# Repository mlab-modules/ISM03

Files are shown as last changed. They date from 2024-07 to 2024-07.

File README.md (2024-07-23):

# ISM03 - Si4463-based transceiver with SPI interface

The ISM03 is a high-performance wireless transceiver designed for long-distance data transmission. The module is based on the [Si4463 chip](https://www.silabs.com/wireless/proprietary/ezradiopro-sub-ghz-ics/device.si4463?tab=specs) from Silicon Labs. It has a wide frequency range and output power, it is ideal for applications that require robust and reliable wireless communication.

ISM03 can operate on the open 433 or 868 MHz frequencies, which are popular in many applications.

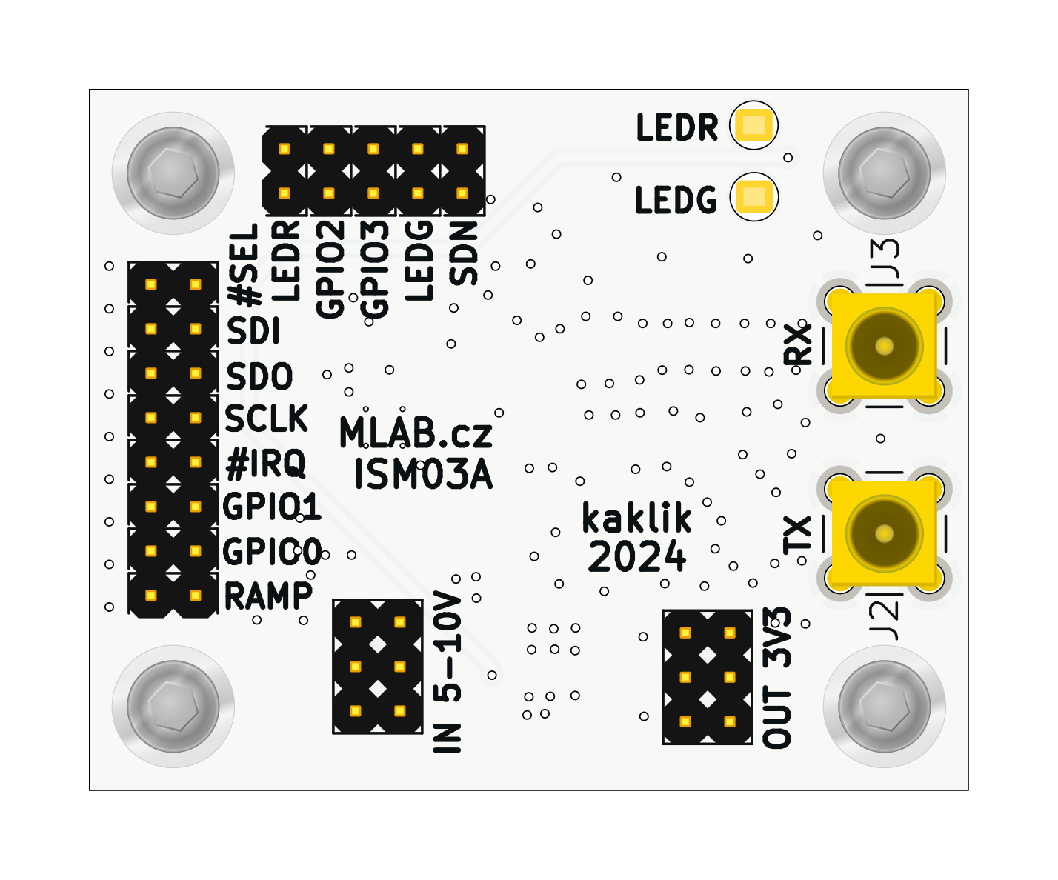
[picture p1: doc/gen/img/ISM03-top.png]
Top view on ISM03

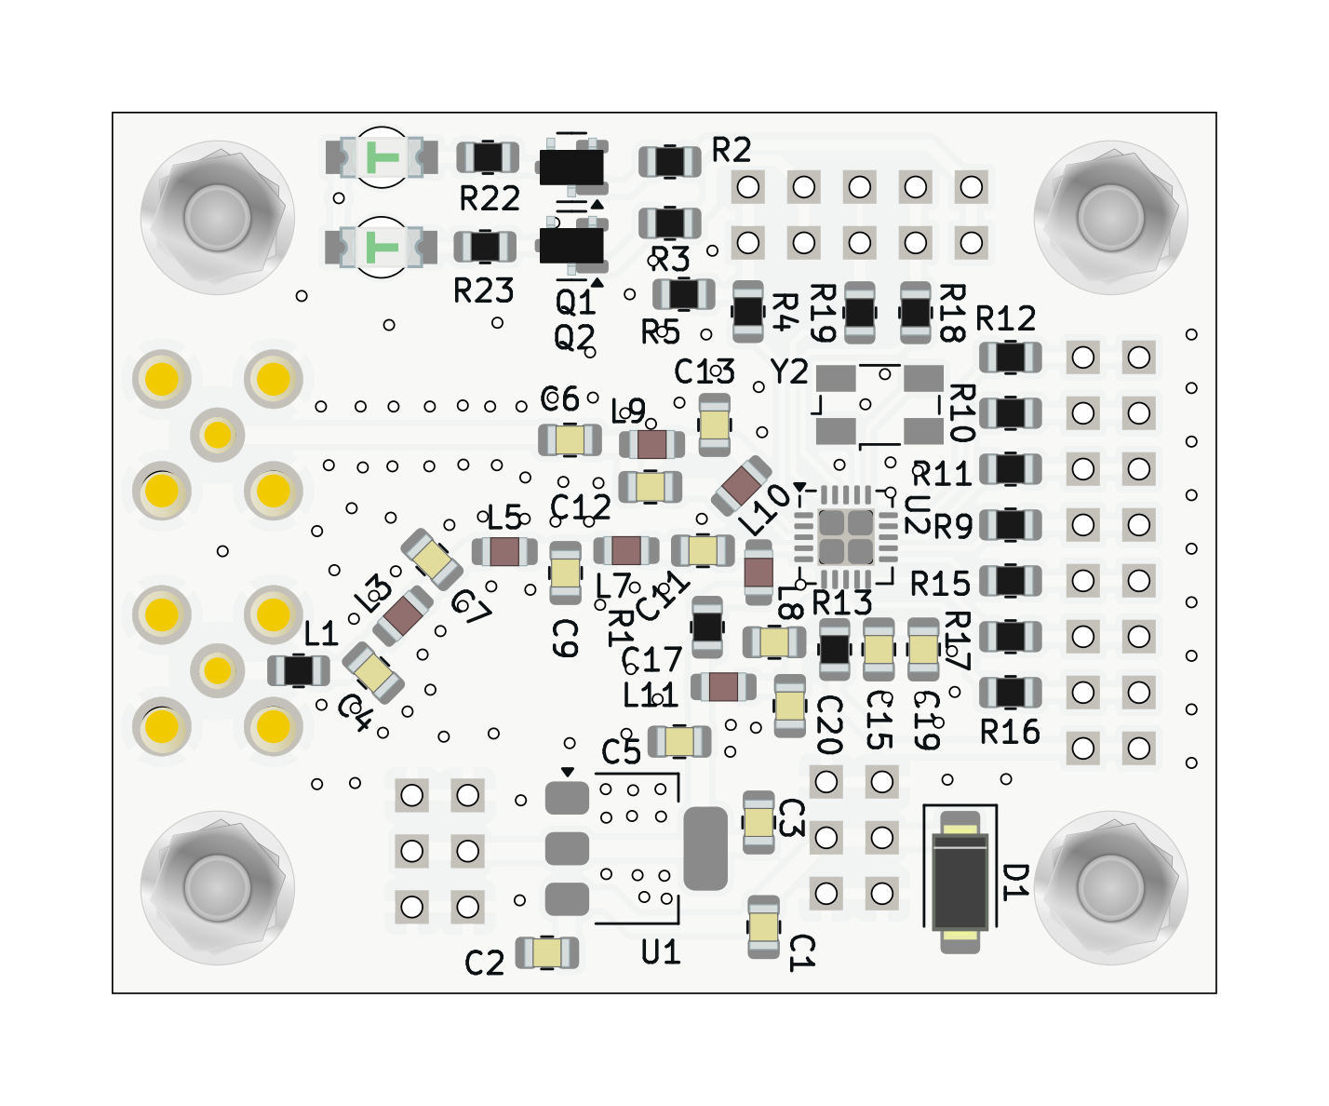
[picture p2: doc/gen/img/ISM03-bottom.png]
Bottom view on ISM03


## Parameters

- Based on the Si4463 chip
- Chip frequency range: 142 to 1050 MHz, with the ability to operate on the open 433 or 868 MHz frequencies
- Chip output power: -20 to 20 dBm
- The Si4463 chip includes a programmable block capable of controlling radio settings and supports the SPI interface
- Power supply: 5-12V with integrated 3.3V stabilizer
- Communication: SPI, GPIO
- Accessible GPIO signals directly from the transceiver
- Status indication: Two LEDs controlled from the Si chip
- Antenna connectors: MCX for RX and TX antennas. For bidirectional communication with a single antenna, connecting the [RFSWITCH module](www.mlab.cz/module/RFSWITCH01/) is recommended, which serves as an RF switch and enables MIMO 2x2 support. ISM03 can control the RFSWITCH module through GPIO pins

## Possible Applications

The MLAB ISM03 module with the Si4463 transceiver is suitable for various applications. It can be used in areas such as:

- **Remote Control**: The module can be used for wireless control of various devices, such as drones, RC cars, or home automation.
- **Data Links**: With a suitable firmware, the module can function as a [SiK data communication link](https://ardupilot.org/copter/docs/common-sik-telemetry-radio.html), which can transmit [MAVLink packets](https://mavlink.io/en/). MAVLink is a protocol designed for communication with unmanned vehicles and is supported by the most widespread autopilots Ardupilot and PX4. This is ideal for applications that require wireless data transmission.
- **Wireless Sensor Networks**: The module can be used to create wireless sensor networks in IoT applications.

> Based on this module, the company [ThunderFly](https://www.thunderfly.cz) has developed a module optimized for use on drones, which combines this ISM03 module, RFSWITCH01A, and additional RF filters and LNA. That could be integrated directly to the autopilot PCB to save weight.

## Links to Related Resources

- [Silicon Labs Si4463 Product Page](https://www.silabs.com/wireless/proprietary/ezradiopro-sub-ghz-ics/device.si4463?tab=specs)
- [Si4463 Datasheet](https://www.silabs.com/documents/public/data-sheets/Si4464-63-61-60.pdf)
- [MavLink Protocol](https://mavlink.io/en/)
- [SiK Radio](https://ardupilot.org/copter/docs/common-sik-telemetry-radio.html)
- [EZRADioPRO Family](https://www.silabs.com/wireless/proprietary/ezradiopro-sub-ghz-ics)
- [TFSIK01 Module by ThunderFly](https://github.com/ThunderFly-aerospace/TFSIK01/)

---

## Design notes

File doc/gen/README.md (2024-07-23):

# PCB

Board size: 50.29x40.13 mm (1.98x1.58 inches)

- This is the size of the rectangle that contains the board
- Thickness: 1.6 mm (63 mils)
- Material: FR4
- Finish: None
- Layers: 2
- Copper thickness: 35 µm

Solder mask: TOP / BOTTOM

- Color: Green

Silk screen: TOP / BOTTOM

- Color: White

Stackup:

| Name | Type | Color | Thickness | Material | Epsilon_r | Loss tangent |
|---|---|---|---|---|---|---|
| F.SilkS | Top Silk Screen | | | | | |
| F.Mask | Top Solder Mask | | 10 | | | |
| F.Cu | copper | | 35 | | | |
| dielectric 1 | core | | 1510 | FR4 | 4.5 | 0.020 |
| B.Cu | copper | | 35 | | | |
| B.Mask | Bottom Solder Mask | | 10 | | | |
| B.Paste | Bottom Solder Paste  | | | | | |
| B.SilkS | Bottom Silk Screen | | | | | |

# Important sizes

Clearance: 0.2 mm (8 mils)

Track width: 0.25 mm (10 mils)

- By design rules: 0.2 mm (8 mils)

Drill: 0.3 mm (12 mils)

- Vias: 0.5 mm (20 mils) [Design: 0.3 mm (12 mils)]
- Pads: 0.3 mm (12 mils)
- The above values are real drill sizes, they add 0.1 mm (4 mils) to plated holes (PTH)

Via: 0.8/0.4 mm (31/16 mils)

- By design rules: 0.4/0.2 mm (16/8 mils)
- Micro via: yes [0.2/0.1 mm (8/4 mils)]
- Buried/blind via: yes
- Total: 110 (thru: 110 buried/blind: 0 micro: 0)

Outer Annular Ring: 0.1 mm (4 mils)

- By design rules: 0.1 mm (4 mils)

Eurocircuits class: 6D
- Using min drill 0.25 mm for an OAR of 0.13 mm

# General stats

Components count: (SMD/THT)

- Top: 0/21 (THT)
- Bottom: 48/0 (SMD)

Defined tracks:

- 0.25 mm (10 mils)
- 0.3 mm (12 mils)
- 0.4 mm (16 mils)
- 0.5 mm (20 mils)
- 0.6 mm (24 mils)
- 0.8 mm (31 mils)
- 0.86 mm (34 mils)

Used tracks:

- 0.25 mm (10 mils) (54) defined: yes
- 0.3 mm (12 mils) (5) defined: yes
- 0.4 mm (16 mils) (6) defined: yes
- 0.5 mm (20 mils) (62) defined: yes
- 0.6 mm (24 mils) (6) defined: yes
- 0.8 mm (31 mils) (43) defined: yes

Defined vias:

Used vias:

- 0.8/0.4 mm (31/16 mils) (Count: 110, Aspect: 2.0 A) defined: no

Holes (excluding vias):

- 0.2 mm (8 mils) (4)
- 0.89 mm (35 mils) (38)
- 1.5 mm (59 mils) (2)
- 1.7 mm (67 mils) (8)
- 2.7 mm (106 mils) (2)
- 3.0 mm (118 mils) (4)

Oval holes:

Drill tools (including vias and computing adjusts and rounding):

- 0.3 mm (12 mils) (4)
- 0.5 mm (20 mils) (110)
- 1.0 mm (39 mils) (38)
- 1.6 mm (63 mils) (2)
- 1.8 mm (71 mils) (8)
- 2.7 mm (106 mils) (2)
- 3.1 mm (122 mils) (4)

Solder paste stats:

Using a paste with 87.75 % alloy, that has an specific gravity for the alloy of 7.4 g/cm³
and 1.0 g/cm³ for the flux. This paste has an specific gravity of  4.15 g/cm³.

The stencil thickness is  0.12 mm.

| Side | Pads with paste | Area [mm²] | Paste [g] |
|---|---|---|---|
| Total  | 124 | 160.26 | 0.80 |

Note: this is just an approximation to the theoretical value. Margins of the solder mask and waste aren't computed.

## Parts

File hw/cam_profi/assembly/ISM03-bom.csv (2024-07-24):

Component | Description | Part | References | Value | Footprint | Quantity Per PCB | Datasheet | ust_id
1 | Unpolarized capacitor, small symbol | C_Small | C12 | 2.2pF | C_0805_2012Metric | 1 | ~ | 5c70984712875079b91f8b27
2 | Unpolarized capacitor, small symbol | C_Small | C13 | 4.7pF | C_0805_2012Metric | 1 | ~ | 5c70984712875079b91f8b2c
3 | Unpolarized capacitor, small symbol | C_Small | C11 | 9.1pF | C_0805_2012Metric | 1 | ~ | 611b60e71287500165a9732d
4 | Unpolarized capacitor, small symbol | C_Small | C4 | 10pF | C_0805_2012Metric | 1 | ~ | 5c70984712875079b91f8b30
5 | Unpolarized capacitor, small symbol | C_Small | C7 | 12pF | C_0805_2012Metric | 1 | ~ | 5c70984712875079b91f8b31
6 | Unpolarized capacitor, small symbol | C_Small | C9 | 15pF | C_0805_2012Metric | 1 | ~ | 5c70984712875079b91f8b32
7 | Unpolarized capacitor, small symbol | C_Small | C15 | 33pF | C_0805_2012Metric | 1 | ~ | 5c70984712875079b91f8b37
8 | Unpolarized capacitor, small symbol | C_Small | C6C17 | 100pF | C_0805_2012Metric | 2 | ~ | 5c70984712875079b91f8b3b
9 | Unpolarized capacitor, small symbol | C_Small | C2C19 | 100nF | C_0805_2012Metric | 2 | ~ | 5c70984712875079b91f8b4c
10 | Unpolarized capacitor, small symbol | C_Small | C1C3C5C20 | 10uF | C_0805_2012Metric | 4 | ~ | 5c70984812875079b91f8bbd
11 | Light emitting diode | LED | D3 | GREEN | LED_1206 | 1 | ~ | 5c70984412875079b91f8895
12 |  | D_ZENER | D1 | M4 | D_SMA | 1 |  | 5c70984512875079b91f88ac
13 | Light emitting diode | LED | D2 | RED | LED_1206 | 1 | ~ | 5c70984412875079b91f8896
14 | 2x01 2.54 mm pitch header, 2 pins next to each other are connected | HEADER_2x01_PARALLEL | J5J6J7J13J14J15J16J17J19J20J21J22J23 | HEADER_2x01_PARALLEL | Straight_2x01 | 13
15 | MLAB modified doubled pinheader connector | JUMP_3X2 | J1J4 | JUMP_3X2 | Straight_2x03 | 2
16 |  | SMA | J2J3 | MCX | SMA6251A13G50 | 2 |  | 5c70984412875079b91f87ac
17 | Inductor, small symbol | L_Small | L1 | 22nH | R_0805_2012Metric | 1 | ~ | 60be80ed1287500165e6c3bb
18 | Inductor, small symbol | L_Small | L5 | 30nH | L_0805_2012Metric | 1 | ~ | 611b69d31287500165a9742b
19 | Inductor, small symbol | L_Small | L7 | 33nH | L_0805_2012Metric | 1 | ~ | 5c70984412875079b91f8808
20 | Inductor, small symbol | L_Small | L3 | 36nH | L_0805_2012Metric | 1 | ~ | 66a10bc36fdfe6f54e2ebbf8
21 | Inductor, small symbol | L_Small | L9 | 56nH | L_0805_2012Metric | 1 | ~ | 5c70984812875079b91f8ba4
22 | Inductor, small symbol | L_Small | L10 | 62nH | L_0805_2012Metric | 1 | ~ | 66a127196fdfe6f54e2ebd35
23 | Inductor, small symbol | L_Small | L8 | 220nH | L_0805_2012Metric | 1 | ~ | 5c70984412875079b91f880d
24 | Inductor with ferrite core | L_Ferrite | L11 | 74279204 | L_0805_2012Metric | 1 | ~ | 6016f01e1287504e4aa85f2a
25 | NPN transistor, base/emitter/collector | Q_NPN_BEC | Q1Q2 | BC817 | SOT-23 | 2 | ~ | 5c70984712875079b91f8aec
26 | Resistor | R | R1 | 3R | R_0805_2012Metric | 1 | ~ | 60d57f1a1287500165f858ae
27 | Resistor | R | R4R9R10R11R12R13R15R16R17R18R19 | 33R | R_0805_2012Metric | 11 | ~ | 5c70984512875079b91f8970
28 | Resistor | R | R22R23 | 150R | R_0805_2012Metric | 2 | ~ | 5c70984512875079b91f897a
29 | Resistor | R | R2R3R5 | 10k | R_0805_2012Metric | 3 | ~ | 5c70984612875079b91f899f
30 | 800mA Low-Dropout Linear Regulator, 3.3V fixed output, SOT-223 | LM1117MP-3.3 | U1 | LM1117MP-3.3 | SOT-223-3_TabPin2 | 1 | http://www.ti.com/lit/ds/symlink/lm1117.pdf | 5c70984712875079b91f8af9
31 | High-Performance, Low-Current Sub-GHz Transceiver, +20dBm, Major bands 142-1050 MHz, QFN-20 | Si4463 | U2 | Si4463 | QFN-20-1EP_4x4mm_P0.5mm_EP2.6x2.6mm_ThermalVias | 1 | https://www.silabs.com/documents/public/data-sheets/Si4464-63-61-60.pdf | 5c70984612875079b91f8a0a
32 | Four pin crystal, GND on pins 2 and 4 | Crystal_GND24 | Y2 | ABM3B-30.000MHZ-10-1-U-T | Crystal_SMD_Abracon_ABM3B-4Pin_5.0x3.2mm | 1 | ~ | 5c70984712875079b91f8ba1

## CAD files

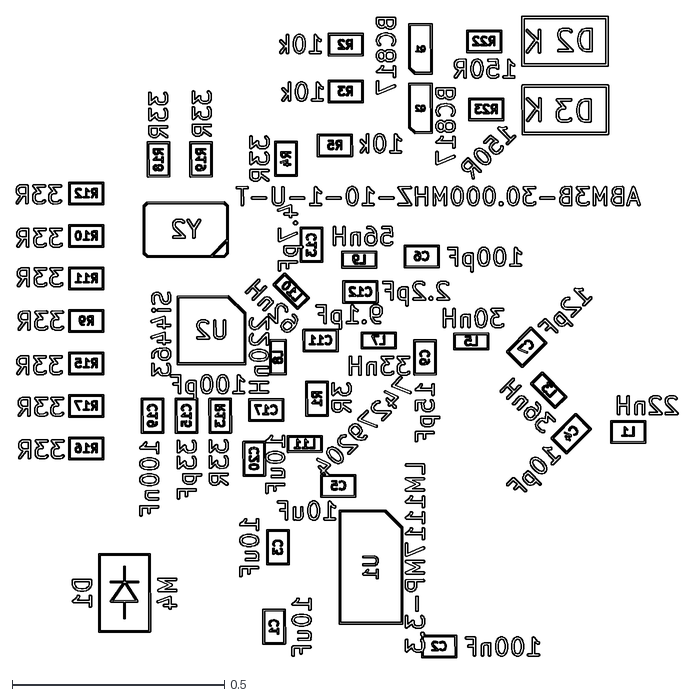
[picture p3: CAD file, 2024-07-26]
doc/gen/dxf/ISM03-B_Fab.dxf
1.56 x 1.51

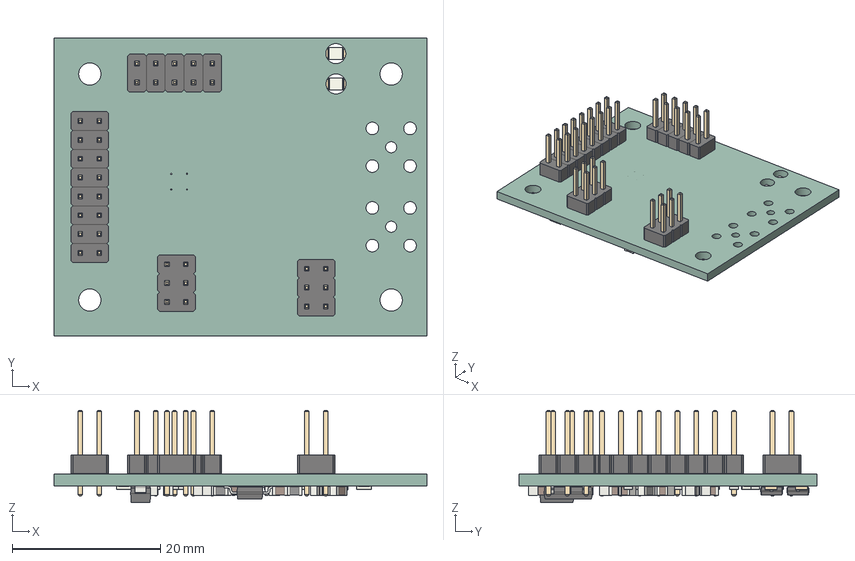
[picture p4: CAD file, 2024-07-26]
doc/gen/ISM03.step
50.3 x 40.1 x 12.5 mm
PinHeader_2x01_P254mm_Vertical x 13
PinHeader_2x03_P254mm_Vertical x 2
R_0805_2012Metric x 18
SOT_223
SOT_23 x 2
LED_1206_3216Metric x 2
C_0805_2012Metric x 15
D_SMA
L_0805_2012Metric x 7
kibot_2bm9_34z_PCB

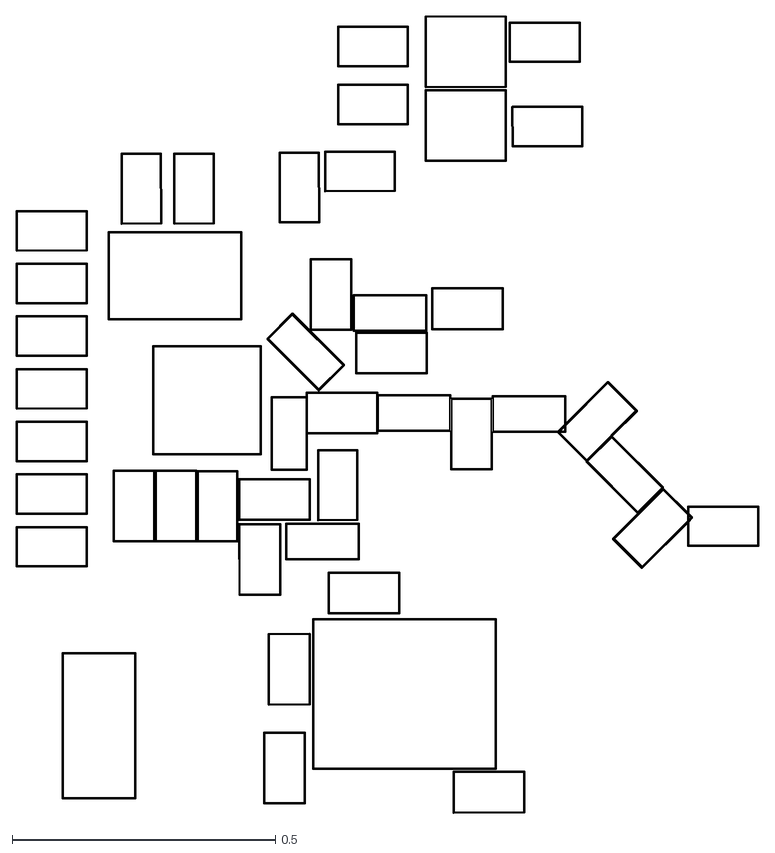
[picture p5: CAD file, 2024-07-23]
doc/gen/dxf/ISM03-B_Courtyard.dxf
1.41 x 1.51

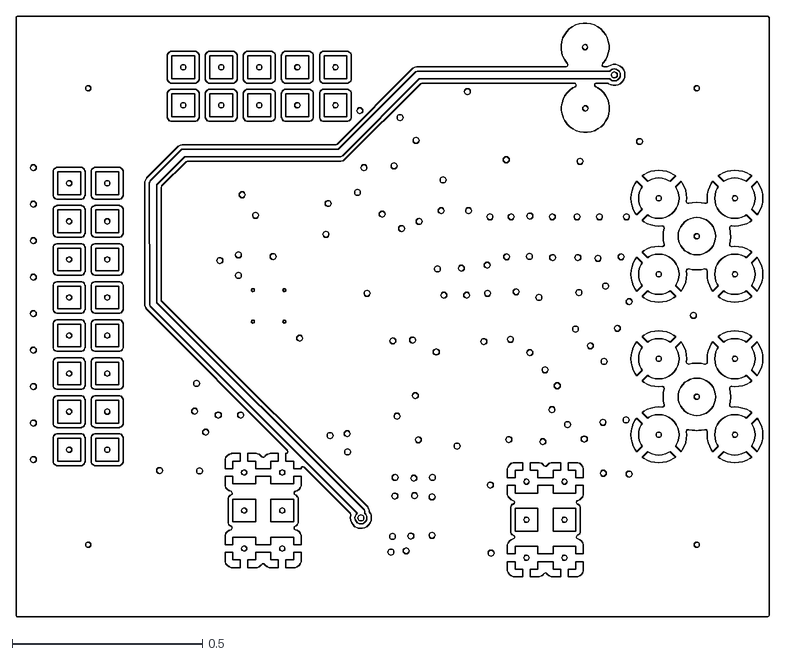
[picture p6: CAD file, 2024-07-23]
doc/gen/dxf/ISM03-F_Cu.dxf
1.98 x 1.58

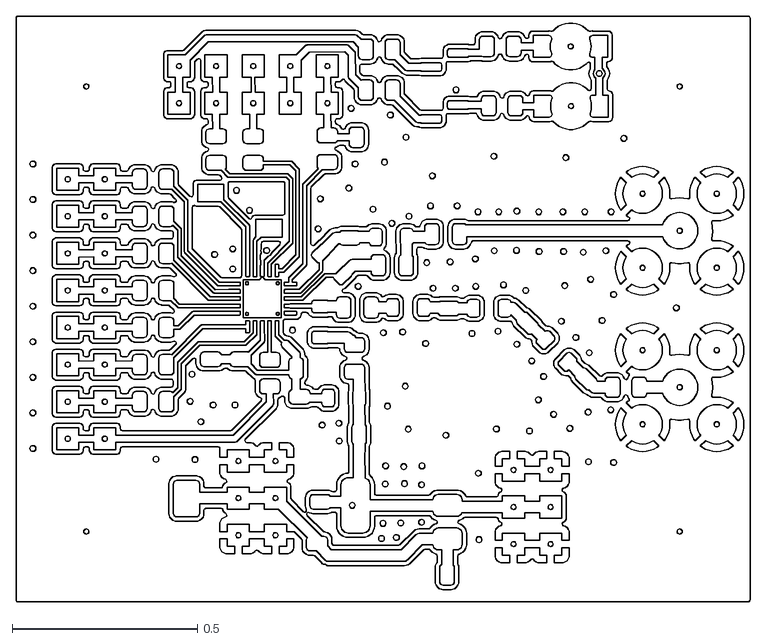
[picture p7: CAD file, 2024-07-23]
doc/gen/dxf/ISM03-B_Cu.dxf
1.98 x 1.58

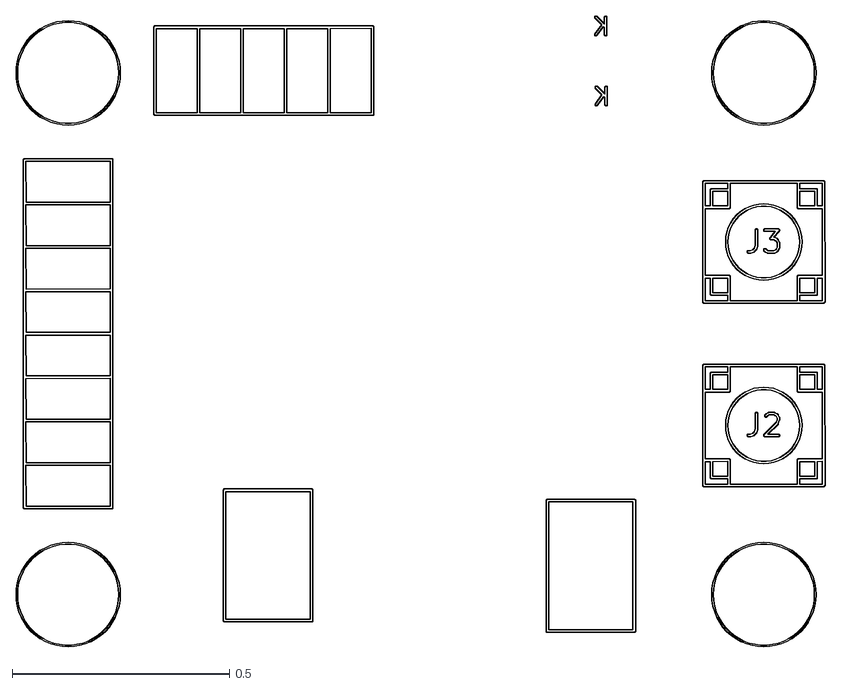
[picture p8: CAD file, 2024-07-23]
doc/gen/dxf/ISM03-F_Fab.dxf
1.86 x 1.45

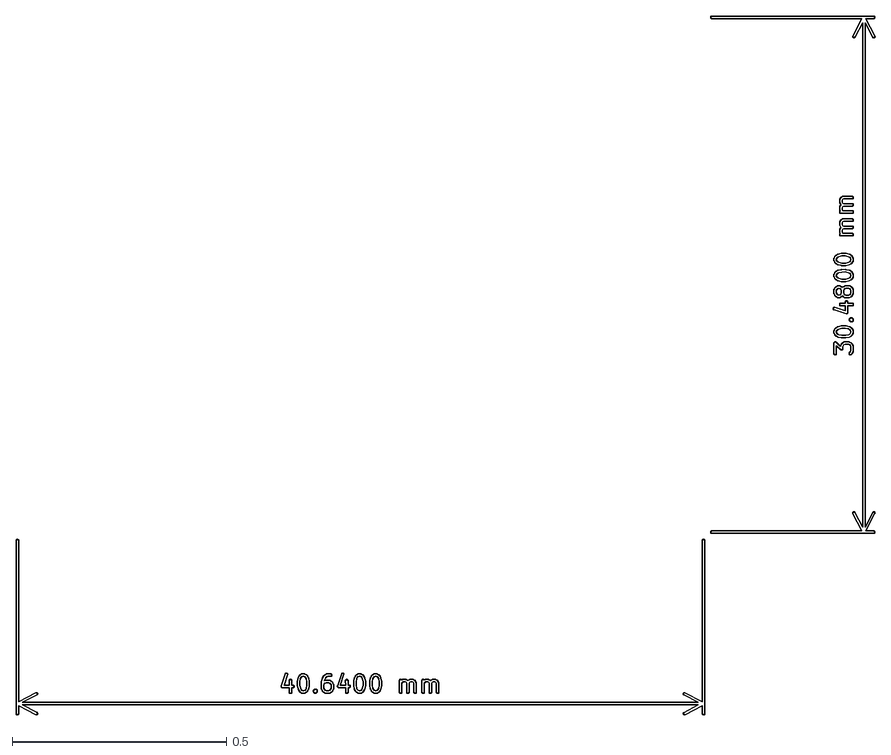
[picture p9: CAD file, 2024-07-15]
doc/gen/dxf/ISM03-User_Comments.dxf
2.00 x 1.63

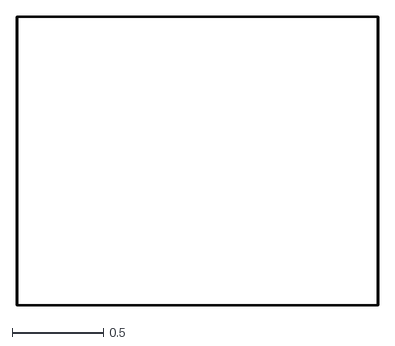
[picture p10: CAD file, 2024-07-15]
doc/gen/dxf/ISM03-Edge_Cuts.dxf
1.99 x 1.59

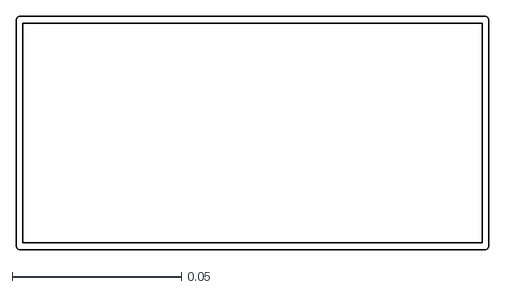
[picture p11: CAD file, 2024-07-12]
doc/gen/dxf/ISM03-F_Courtyard.dxf
0.14 x 0.0689

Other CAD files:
doc/gen/dxf/ISM03-User_Drawings.dxf
doc/gen/dxf/ISM03-B_Mask.dxf
doc/gen/dxf/ISM03-B_Paste.dxf
doc/gen/dxf/ISM03-B_Silkscreen.dxf
doc/gen/dxf/ISM03-F_Mask.dxf
doc/gen/dxf/ISM03-F_Silkscreen.dxf

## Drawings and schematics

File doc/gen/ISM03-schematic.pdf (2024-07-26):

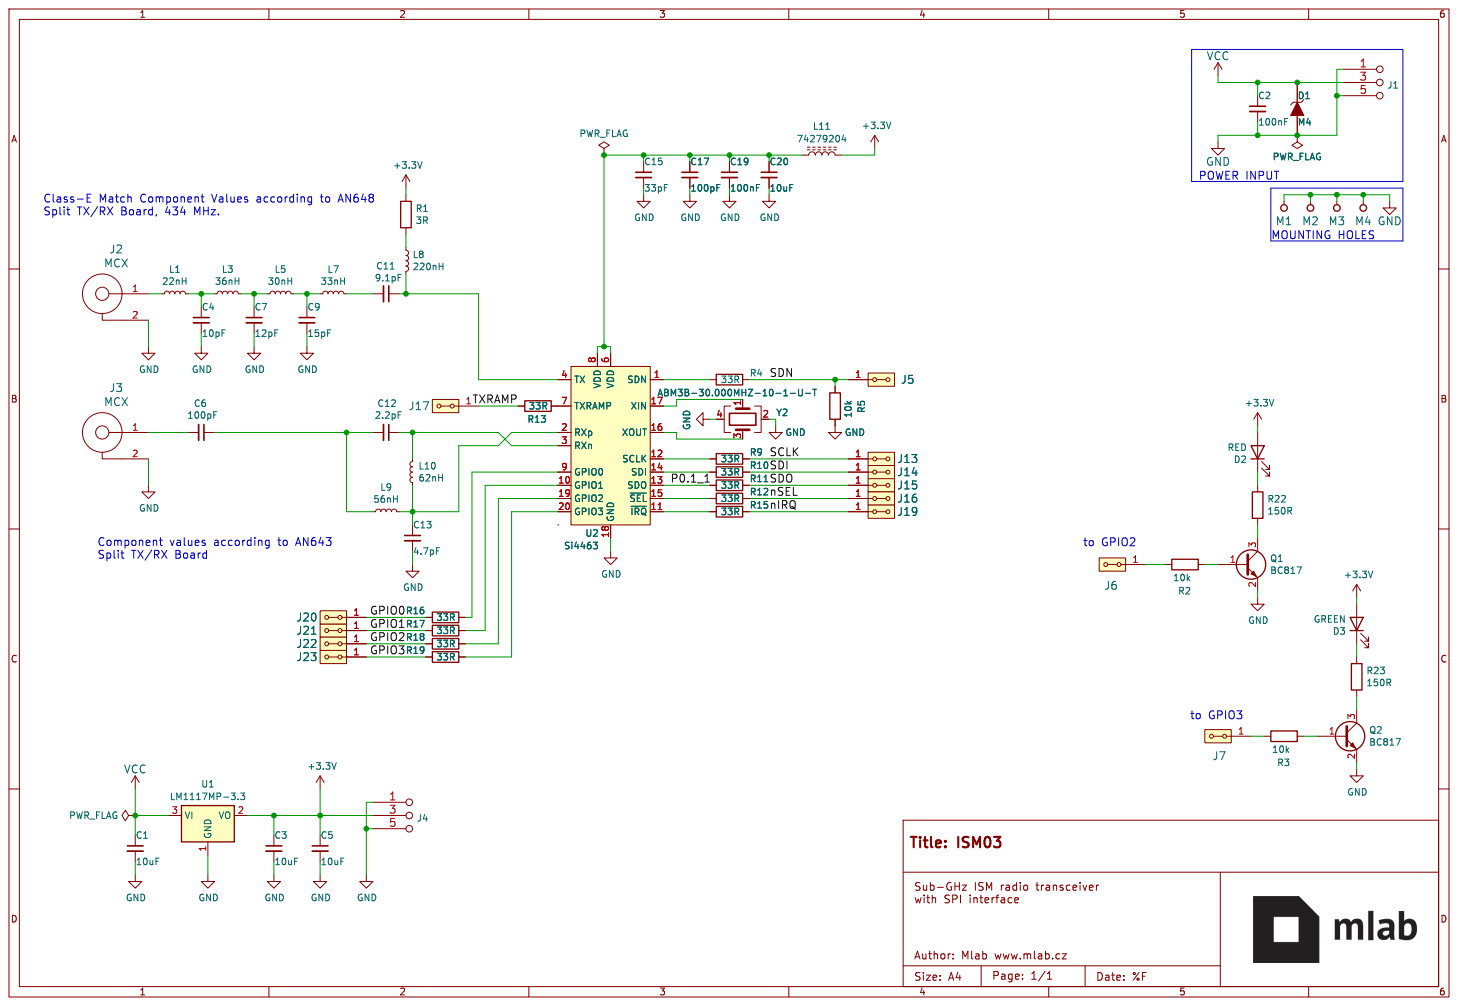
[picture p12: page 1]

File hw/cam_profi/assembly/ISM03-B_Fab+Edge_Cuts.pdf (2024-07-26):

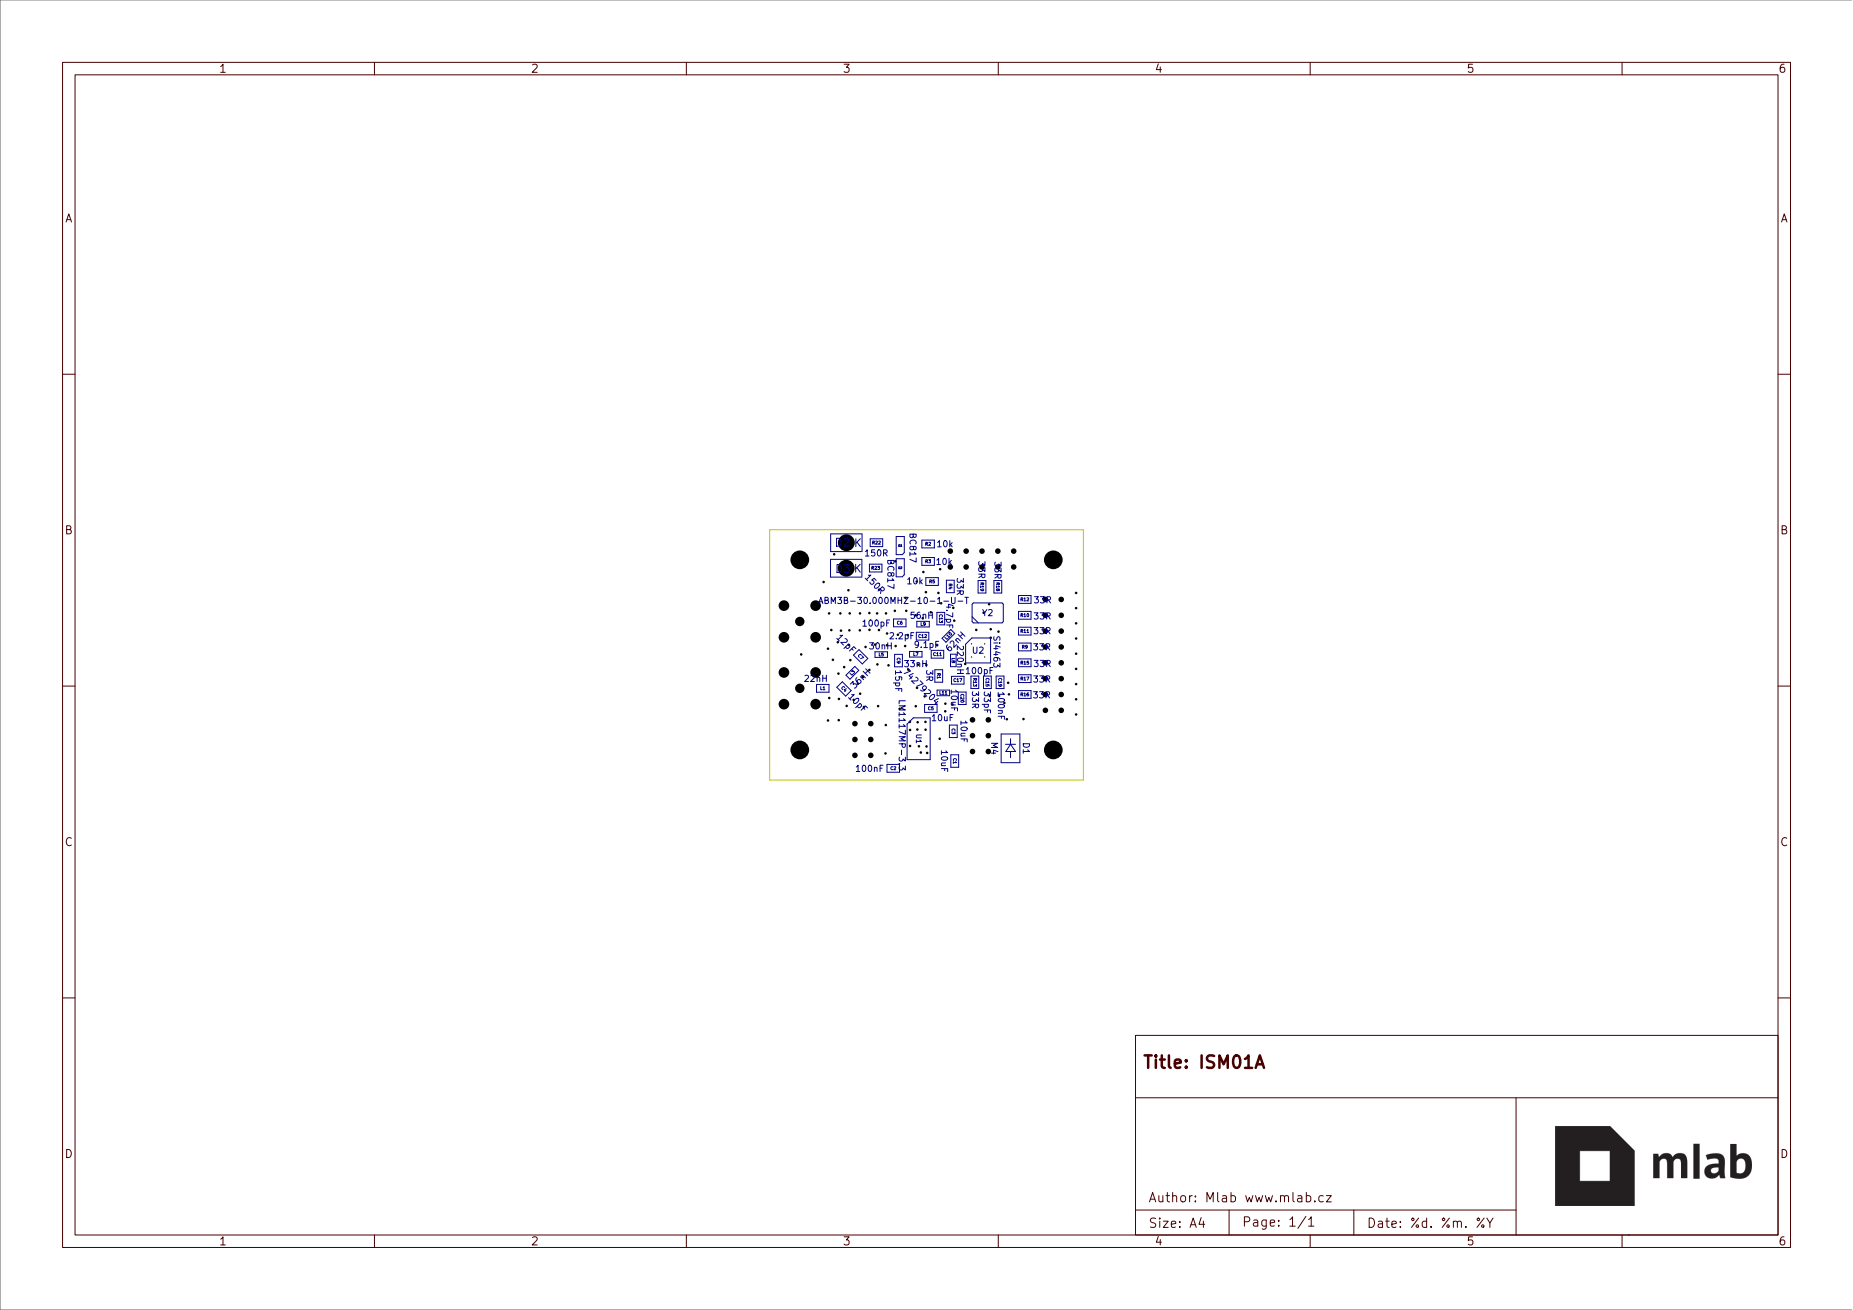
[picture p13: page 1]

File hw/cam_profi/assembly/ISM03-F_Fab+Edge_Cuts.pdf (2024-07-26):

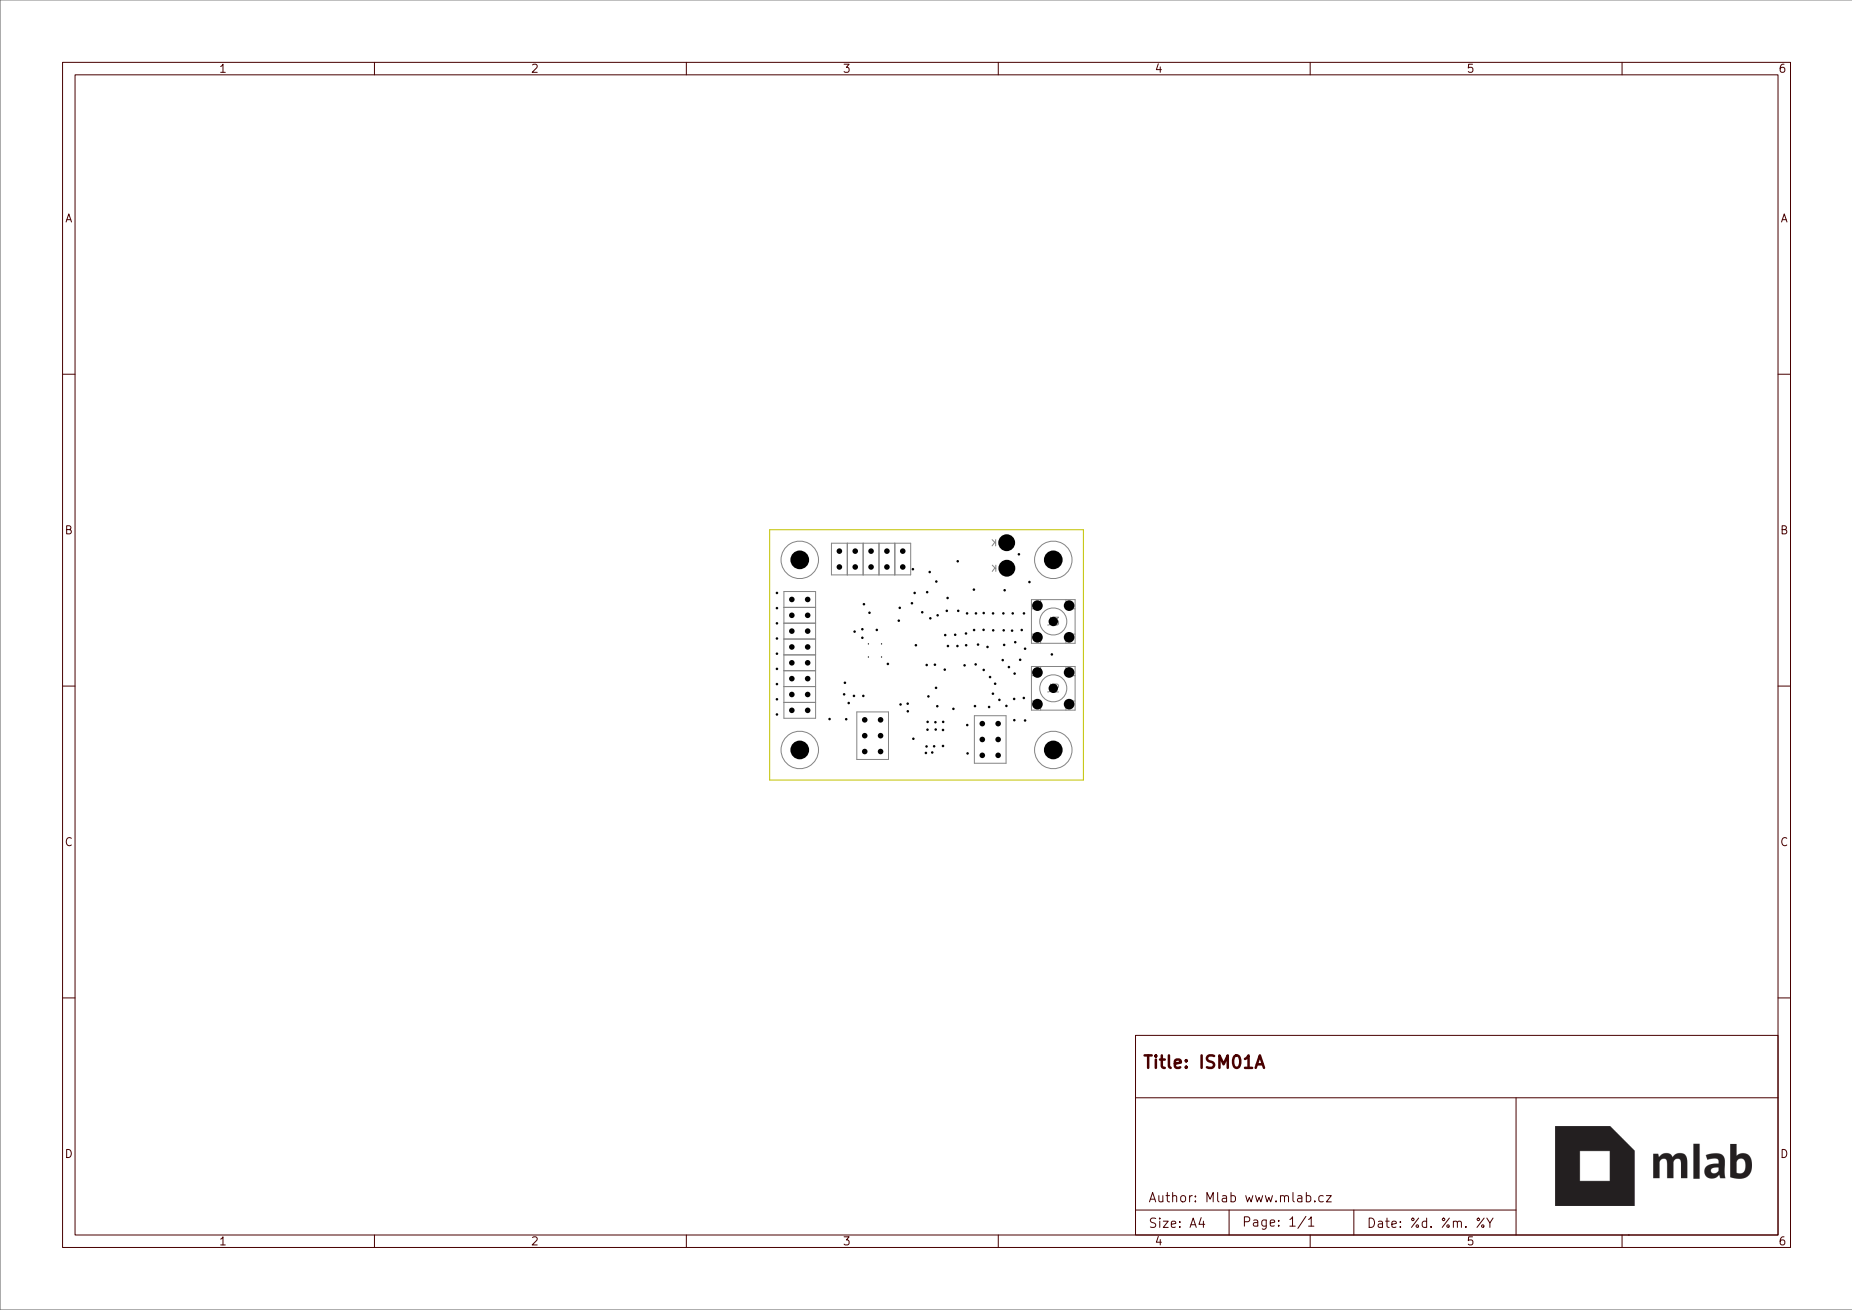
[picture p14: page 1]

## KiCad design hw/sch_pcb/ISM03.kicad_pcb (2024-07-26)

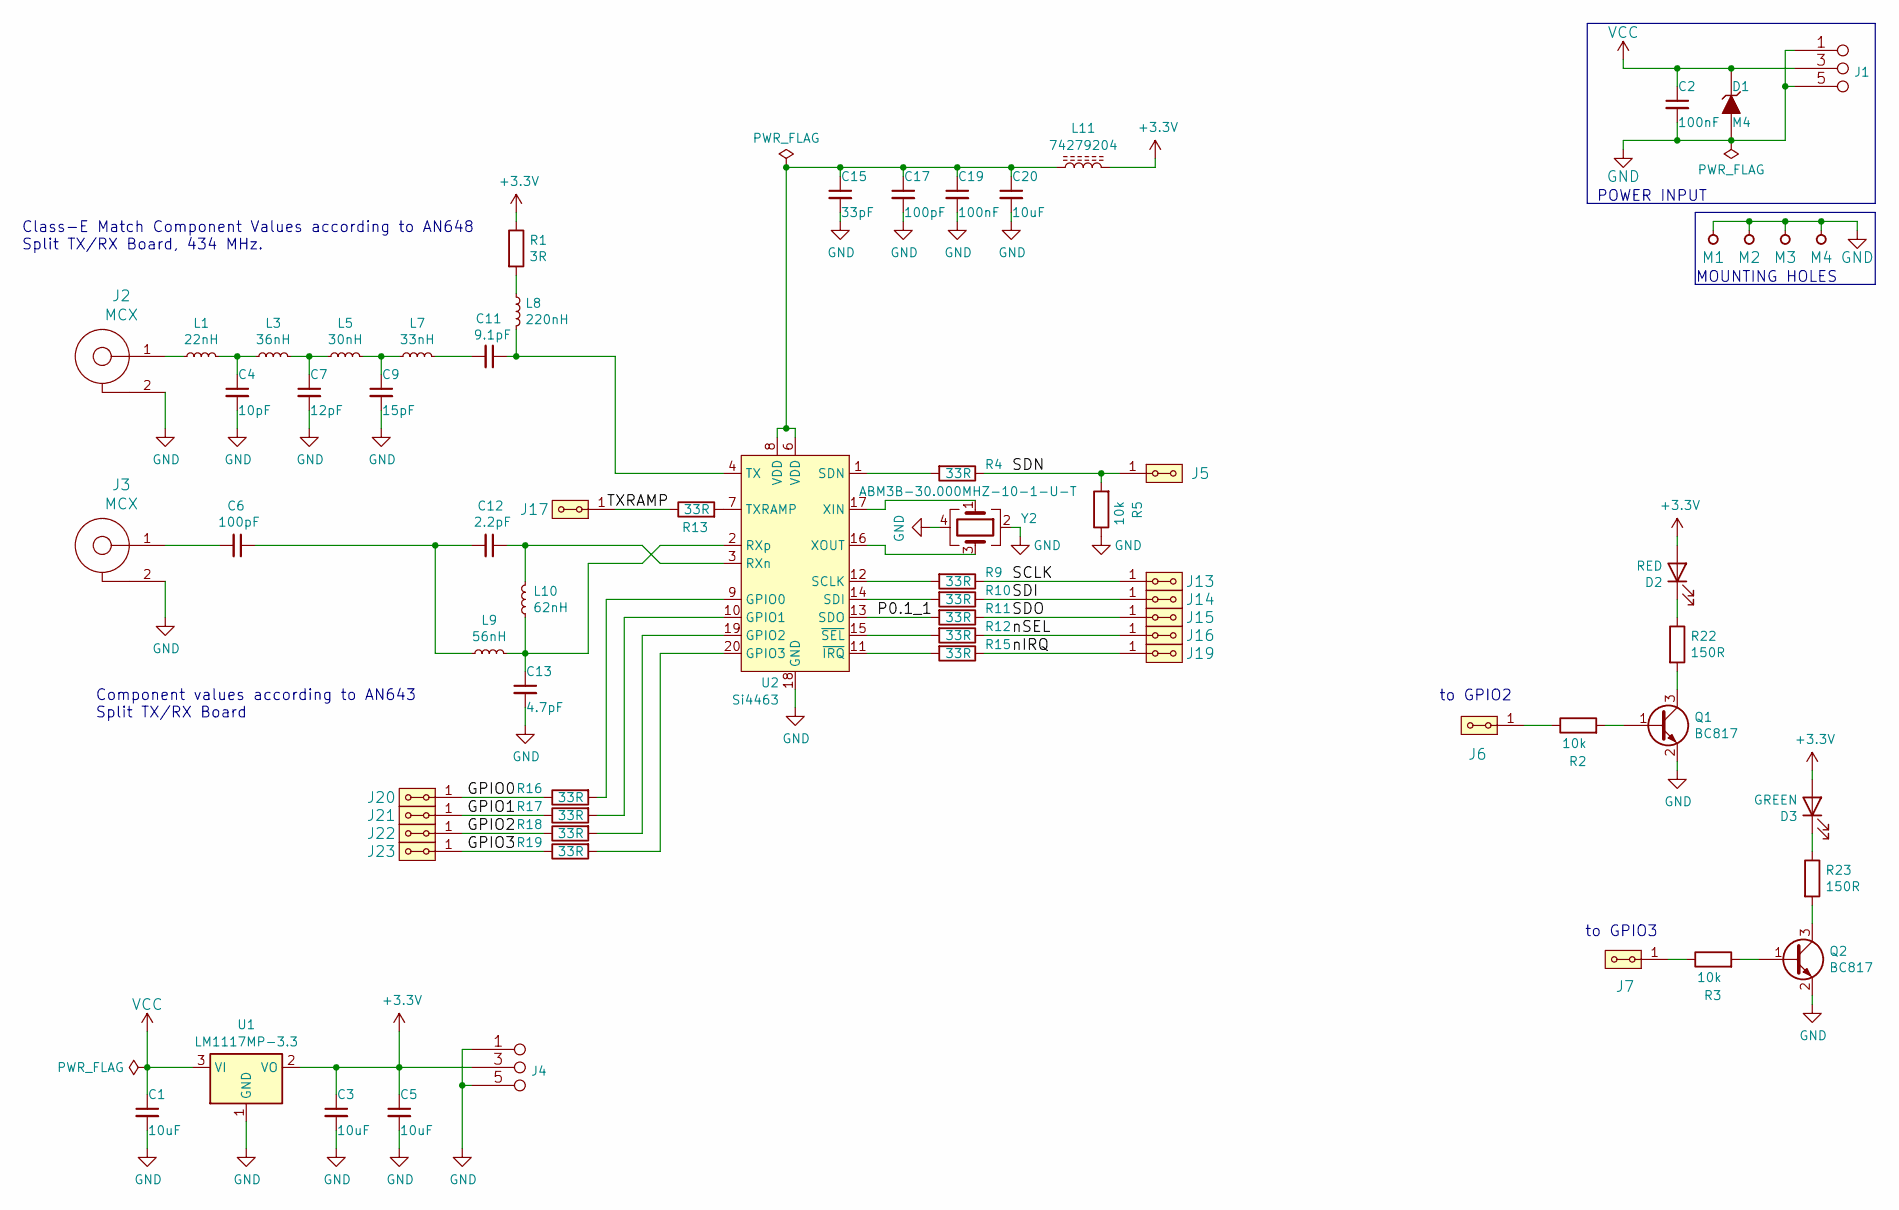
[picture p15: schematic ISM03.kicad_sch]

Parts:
C1, C3, C5, C20: 10uF; C_0805_2012Metric
C2, C19: 100nF; C_0805_2012Metric
C4: 10pF; C_0805_2012Metric
C6, C17: 100pF; C_0805_2012Metric
C7: 12pF; C_0805_2012Metric
C9: 15pF; C_0805_2012Metric
C11: 9.1pF; C_0805_2012Metric
C12: 2.2pF; C_0805_2012Metric
C13: 4.7pF; C_0805_2012Metric
C15: 33pF; C_0805_2012Metric
D1: M4; D_SMA
D2: RED; LED_1206
D3: GREEN; LED_1206
J1, J4: JUMP_3X2; Straight_2x03
J2, J3: MCX; SMA6251A13G50
J5, J6, J7, J13, J14, J15, J16, J17, J19, J20, J21, J22, J23: HEADER_2x01_PARALLEL; Straight_2x01
L1: 22nH; R_0805_2012Metric
L3: 36nH; L_0805_2012Metric
L5: 30nH; L_0805_2012Metric
L7: 33nH; L_0805_2012Metric
L8: 220nH; L_0805_2012Metric
L9: 56nH; L_0805_2012Metric
L10: 62nH; L_0805_2012Metric
L11: 74279204; L_0805_2012Metric
M1, M2, M3, M4: HOLE; MountingHole_3mm
Q1, Q2: BC817; SOT-23
R1: 3R; R_0805_2012Metric
R2, R3, R5: 10k; R_0805_2012Metric
R4, R9, R10, R11, R12, R13, R15, R16, R17, R18, R19: 33R; R_0805_2012Metric
R22, R23: 150R; R_0805_2012Metric
U1: LM1117MP-3.3; SOT-223-3_TabPin2
U2: Si4463; QFN-20-1EP_4x4mm_P0.5mm_EP2.6x2.6mm_ThermalVias
Y2: ABM3B-30.000MHZ-10-1-U-T; Crystal_SMD_Abracon_ABM3B-4Pin_5.0x3.2mm

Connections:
+3.3V: C3.1, C5.1, D2.2 (A), D3.2 (A), J4.3 (4), J4.4, L11.2, R1.1, U1.2 (VO)
/GPIO0: J20.1, J20.2, R16.1
/GPIO1: J21.1, J21.2, R17.1
/GPIO2: J22.1, J22.2, R18.1
/GPIO3: J23.1, J23.2, R19.1
/P0.1_1: R11.2, U2.13 (SDO)
/SCLK: J13.1, J13.2, R9.1
/SDI: J14.1, J14.2, R10.1
/SDN: J5.1, J5.2, R4.1, R5.2
/SDO: J15.1, J15.2, R11.1
/TXRAMP: J17.1, J17.2, R13.1
/nIRQ: J19.1, J19.2, R15.1
/nSEL: J16.1, J16.2, R12.1
GND: C1.2, C2.2, C3.2, C4.2, C5.2, C7.2, C9.2, C13.2, C15.2, C17.2, C19.2, C20.2, D1.2 (A), J1.1 (2), J1.2, J1.5 (6), J1.6, J2.2, J3.2, J4.1 (2), J4.2, J4.5 (6), J4.6, M1.1, M2.1, M3.1, M4.1, Q1.2 (E), Q2.2 (E), R5.1, U1.1 (GND), U2.18 (GND), U2.21 (GND), Y2.2, Y2.4
unnamed: C4.1, L1.2, L3.1
unnamed: C6.2, J3.1
unnamed: C7.1, L3.2, L5.1
unnamed: C9.1, L5.2, L7.1
unnamed: C11.2, L7.2
unnamed: C6.1, C12.2, L9.1
unnamed: C15.1, C17.1, C19.1, C20.1, L11.1, U2.6 (VDD), U2.8 (VDD)
unnamed: D2.1 (K), R22.1
unnamed: D3.1 (K), R23.1
unnamed: J2.1, L1.1
unnamed: J6.1, J6.2, R2.1
unnamed: J7.1, J7.2, R3.1
unnamed: L8.1, R1.2
unnamed: Q1.1 (B), R2.2
unnamed: Q1.3 (C), R22.2
unnamed: Q2.1 (B), R3.2
unnamed: Q2.3 (C), R23.2
unnamed: R16.2, U2.9 (GPIO0)
unnamed: R17.2, U2.10 (GPIO1)
unnamed: R18.2, U2.19 (GPIO2)
unnamed: R19.2, U2.20 (GPIO3)
unnamed: C12.1, L10.2, U2.3 (RXn)
unnamed: C13.1, L9.2, L10.1, U2.2 (RXp)
unnamed: R9.2, U2.12 (SCLK)
unnamed: R10.2, U2.14 (SDI)
unnamed: R4.2, U2.1 (SDN)
unnamed: C11.1, L8.2, U2.4 (TX)
unnamed: R13.2, U2.7 (TXRAMP)
unnamed: U2.17 (XIN), Y2.1
unnamed: U2.16 (XOUT), Y2.3
unnamed: R15.2, U2.11 (~IRQ)
unnamed: R12.2, U2.15 (~SEL)
VCC: C1.1, C2.1, D1.1 (K), J1.3 (4), J1.4, U1.3 (VI)

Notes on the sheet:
POWER INPUT
Component values according to AN643 Split TX/RX Board
to GPIO3
to GPIO2
Class-E Match Component Values according to AN648 Split TX/RX Board, 434 MHz.
MOUNTING HOLES

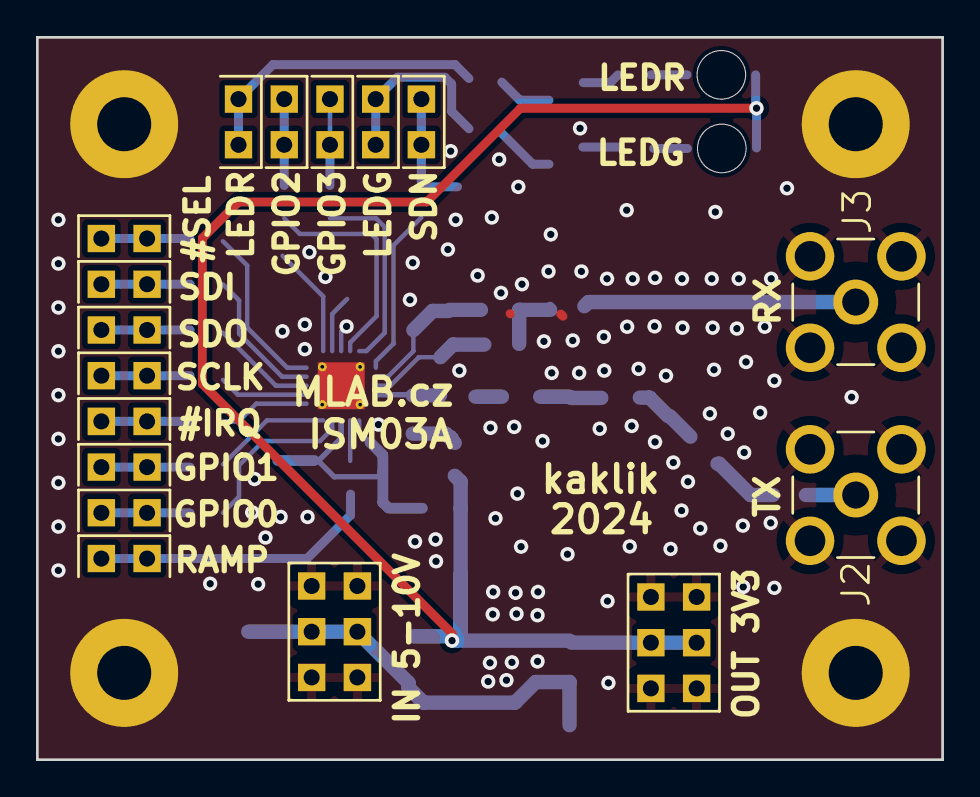
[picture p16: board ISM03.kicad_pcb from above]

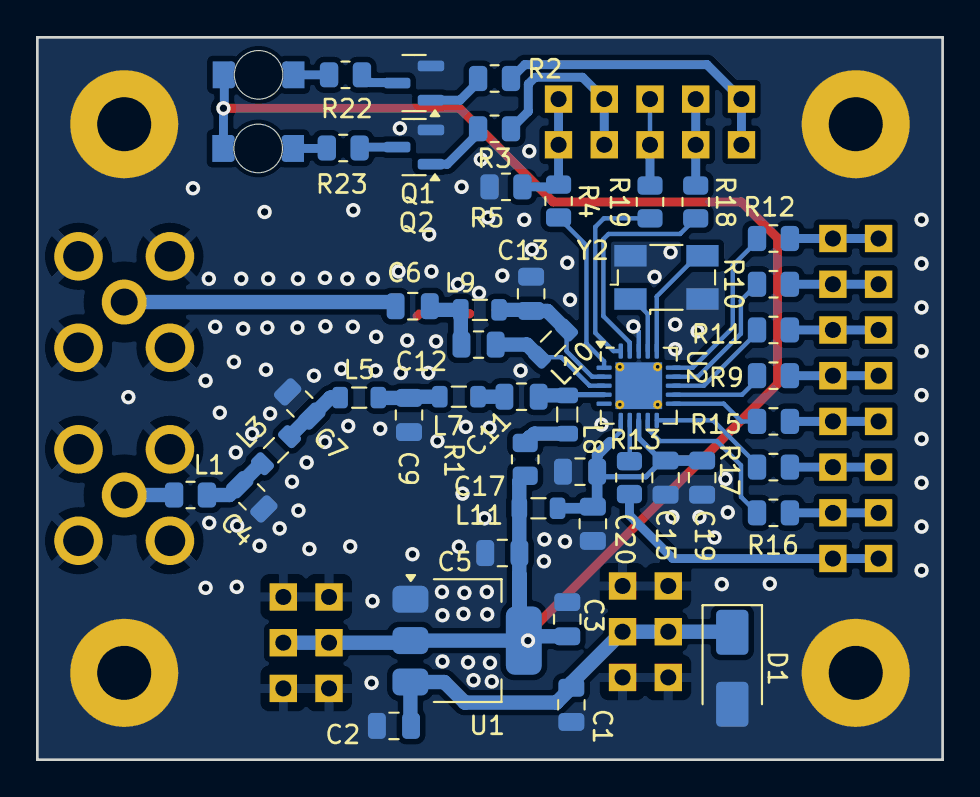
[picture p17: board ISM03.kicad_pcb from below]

Board: 2 copper layers, 50.3 x 40.1 mm, 69 parts (48 on the bottom side), 47 nets.

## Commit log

2024-07-12 Symplified transceiver WiP.
    [ISM01.kicad_sch, ISM03.kicad_pcb, ISM03.kicad_sch]
2024-07-12 Update actions products
    [ISM01-B_Courtyard.dxf, ISM01-B_Cu.dxf, ISM01-B_Fab.dxf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]
2024-07-13 Update documentation PCB WiP.
    [ISM03.kicad_pcb, ISM03.kicad_sch]
2024-07-13 Backup work before switching to KiCADv8
    [ISM03.kicad_pcb, ISM03.kicad_sch]
2024-07-13 Convert project to KiCAD 8.
    [ISM03.kicad_pcb, ISM03.kicad_sch]
2024-07-14 Routing WiP.
    [ISM03.kicad_pcb, ISM03.kicad_sch]
2024-07-14 Roughtly routet PCB.
    [ISM03.kicad_pcb, ISM03.kicad_sch]
2024-07-15 Fix silksceen.
    [ISM03.kicad_pcb]
2024-07-23 Cleanup layout. Correcly move References and texts.
    [ISM03.kicad_pcb]
2024-07-23 Improve Layout, silkscreen Update footprint from libraries.
    [ISM03.kicad_pcb, ISM03.kicad_sch]
2024-07-24 Removing old files.
    [ISM01A-B.Cu.gbr, ISM01A-B.Mask.gbr, ISM01A-Edge.Cuts.gbr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]
2024-07-24 Update components identification.
    [ISM03.kicad_pcb, ISM03.kicad_sch]
2024-07-24 Fix inductor type.
    [ISM03.kicad_pcb, ISM03.kicad_sch]
2024-07-26 Fix fab layer.
    [ISM03.kicad_pcb]
